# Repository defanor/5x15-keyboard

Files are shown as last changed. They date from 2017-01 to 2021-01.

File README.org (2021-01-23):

* A 5x15 keyboard
This is a keyboard project. That's also my first hardware project, so
in case if somebody would want to reuse it, be careful. Though I've
built it and it works.

The keyboard has 5 rows and 15 columns (well, depends on how one
counts, but approximately that much), and intended to be handy for
emacs: has plenty of accessible modifier keys, and never requires to
get too far from the home row.

More information, photos, and the build process description can be
found in the "[[https://defanor.uberspace.net/notes/building-a-keyboard.xhtml][building a keyboard]]" note.

** Dependencies and software
The switches are borrowed from [[https://www.ergodox.io/][ergodox]] (and altered a bit), and the
[[https://github.com/LuisDiazUgena/Teensy-3.1][LuisDiazUgena/Teensy-3.1]] library for kicad is used. KiCad and LibreCAD
were used, by the way.

For the firmware, I've used PaulStoffregen/{[[https://github.com/PaulStoffregen/cores][cores]],
[[https://github.com/PaulStoffregen/teensy_loader_cli][teensy_loader_cli]]}. Changes introduced to ~teensy3/Makefile~:

#+BEGIN_EXAMPLE
 # configurable options
-OPTIONS = -DF_CPU=48000000 -DUSB_SERIAL -DLAYOUT_US_ENGLISH -DUSING_MAKEFILE
+OPTIONS = -DF_CPU=48000000 -DUSB_KEYBOARDONLY -DLAYOUT_US_ENGLISH -DUSING_MAKEFILE
#+END_EXAMPLE

Then it can be built with ~NO_ARDUINO=1 make~.

** License
Hopefully without violating licenses of the reused bits, this project
is GPL-licensed.

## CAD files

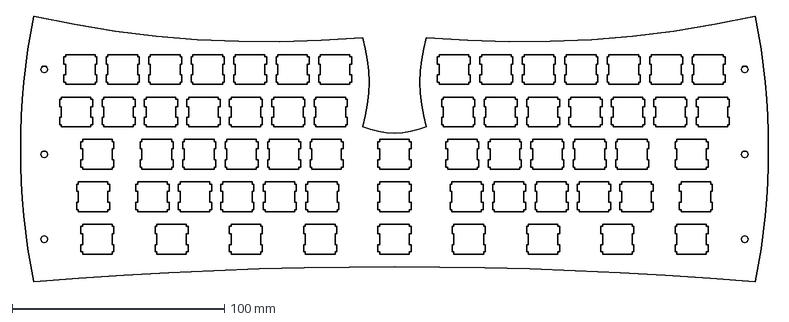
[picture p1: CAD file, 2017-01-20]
dxf/metal-plate-curved-out.dxf
356.5 x 125.0 mm

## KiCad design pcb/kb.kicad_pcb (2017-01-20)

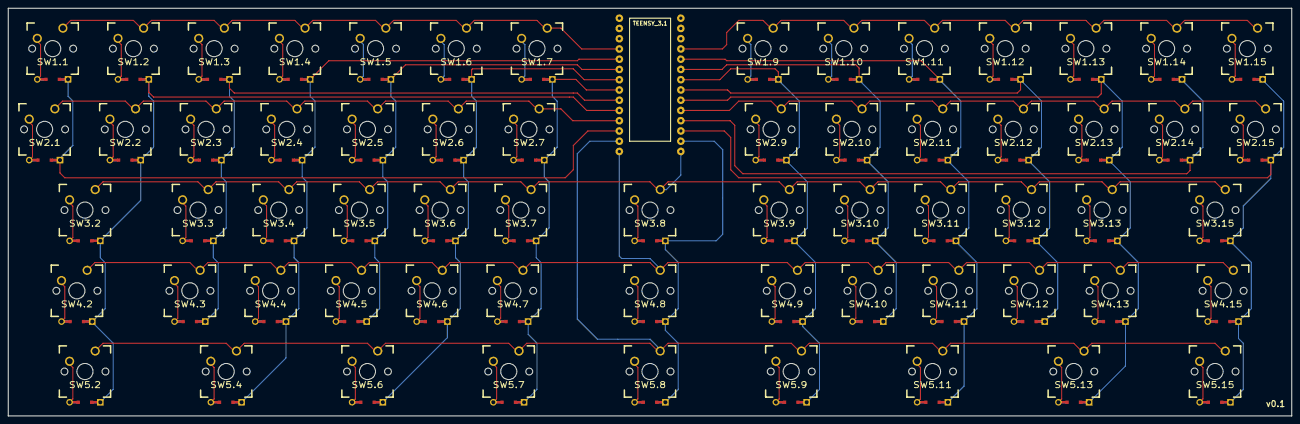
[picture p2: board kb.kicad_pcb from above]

Board: 2 copper layers, 318.0 x 101.0 mm, 64 parts (0 on the bottom side), 85 nets.

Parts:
SW1.1, SW1.2, SW1.3, SW1.4, SW1.5, SW1.6, SW1.7, SW1.9, SW1.10, SW1.11, SW1.12, SW1.13, SW1.14, SW1.15, SW2.1, SW2.2, SW2.3, SW2.4, SW2.5, SW2.6, SW2.7, SW2.9, SW2.10, SW2.11, SW2.12, SW2.13, SW2.14, SW2.15, SW3.3, SW3.4, SW3.5, SW3.6, SW3.7, SW3.9, SW3.10, SW3.11, SW3.12, SW3.13, SW4.3, SW4.4, SW4.5, SW4.6, SW4.7, SW4.9, SW4.10, SW4.11, SW4.12, SW4.13: SWITCH_DIODE; MX_FLIP_DIODE
SW3.2, SW3.8, SW3.15, SW4.2, SW4.8, SW4.15, SW5.2, SW5.4, SW5.6, SW5.7, SW5.8, SW5.9, SW5.11, SW5.13, SW5.15: SWITCH_DIODE; MX_FLIP_DIODE_1_75
U1: TEENSY_3.1

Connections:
/col-1: SW1.1.4, SW2.1.4, U1.10
/col-2: SW1.2.4, SW2.2.4, SW3.2.4, SW4.2.4, SW5.2.4, U1.8
/col-3: SW1.3.4, SW2.3.4, SW3.3.4, SW4.3.4, U1.7
/col-4: SW1.4.4, SW2.4.4, SW3.4.4, SW4.4.4, SW5.4.4, U1.3
/col-5: SW1.5.4, SW2.5.4, SW3.5.4, SW4.5.4, U1.4
/col-6: SW1.6.4, SW2.6.4, SW3.6.4, SW4.6.4, SW5.6.4, U1.5
/col-7: SW1.7.4, SW2.7.4, SW3.7.4, SW4.7.4, SW5.7.4, U1.6
/col-8: SW3.8.4, SW4.8.4, SW5.8.4, U1.14
/col-9: SW1.9.4, SW2.9.4, SW3.9.4, SW4.9.4, SW5.9.4, U1.20
/col-10: SW1.10.4, SW2.10.4, SW3.10.4, SW4.10.4, U1.21
/col-11: SW1.11.4, SW2.11.4, SW3.11.4, SW4.11.4, SW5.11.4, U1.22
/col-12: SW1.12.4, SW2.12.4, SW3.12.4, SW4.12.4, U1.19
/col-13: SW1.13.4, SW2.13.4, SW3.13.4, SW4.13.4, SW5.13.4, U1.18
/col-14: SW1.14.4, SW2.14.4, U1.16
/col-15: SW1.15.4, SW2.15.4, SW3.15.4, SW4.15.4, SW5.15.4, U1.15
/row-1-left: SW1.1.1, SW1.2.1, SW1.3.1, SW1.4.1, SW1.5.1, SW1.6.1, SW1.7.1, U1.2
/row-1-right: SW1.9.1, SW1.10.1, SW1.11.1, SW1.12.1, SW1.13.1, SW1.14.1, SW1.15.1, U1.23
/row-2-left: SW2.1.1, SW2.2.1, SW2.3.1, SW2.4.1, SW2.5.1, SW2.6.1, SW2.7.1, U1.9
/row-2-right: SW2.9.1, SW2.10.1, SW2.11.1, SW2.12.1, SW2.13.1, SW2.14.1, SW2.15.1, U1.17
/row-3: SW3.2.1, SW3.3.1, SW3.4.1, SW3.5.1, SW3.6.1, SW3.7.1, SW3.8.1, SW3.9.1, SW3.10.1, SW3.11.1, SW3.12.1, SW3.13.1, SW3.15.1, U1.13
/row-4: SW4.2.1, SW4.3.1, SW4.4.1, SW4.5.1, SW4.6.1, SW4.7.1, SW4.8.1, SW4.9.1, SW4.10.1, SW4.11.1, SW4.12.1, SW4.13.1, SW4.15.1, U1.12
/row-5: SW5.2.1, SW5.4.1, SW5.6.1, SW5.7.1, SW5.8.1, SW5.9.1, SW5.11.1, SW5.13.1, SW5.15.1, U1.11
unnamed: SW1.9.2, SW1.9.3
unnamed: SW2.9.2, SW2.9.3
unnamed: SW3.9.2, SW3.9.3
unnamed: SW4.9.2, SW4.9.3
unnamed: SW5.9.2, SW5.9.3
unnamed: SW3.8.2, SW3.8.3
unnamed: SW4.8.2, SW4.8.3
unnamed: SW5.8.2, SW5.8.3
unnamed: SW4.11.2, SW4.11.3
unnamed: SW3.10.2, SW3.10.3
unnamed: SW2.10.2, SW2.10.3
unnamed: SW1.10.2, SW1.10.3
unnamed: SW1.11.2, SW1.11.3
unnamed: SW2.11.2, SW2.11.3
unnamed: SW3.11.2, SW3.11.3
unnamed: SW4.10.2, SW4.10.3
unnamed: SW5.11.2, SW5.11.3
unnamed: SW1.5.2, SW1.5.3
unnamed: SW2.5.2, SW2.5.3
unnamed: SW3.5.2, SW3.5.3
unnamed: SW4.5.2, SW4.5.3
unnamed: SW1.6.2, SW1.6.3
unnamed: SW2.6.2, SW2.6.3
unnamed: SW3.6.2, SW3.6.3
unnamed: SW3.4.2, SW3.4.3
unnamed: SW1.4.2, SW1.4.3
unnamed: SW2.4.2, SW2.4.3
unnamed: SW4.4.2, SW4.4.3
unnamed: SW5.4.2, SW5.4.3
unnamed: SW1.7.2, SW1.7.3
unnamed: SW2.7.2, SW2.7.3
unnamed: SW3.7.2, SW3.7.3
unnamed: SW4.7.2, SW4.7.3
unnamed: SW5.7.2, SW5.7.3
unnamed: SW4.6.2, SW4.6.3
unnamed: SW5.6.2, SW5.6.3
unnamed: SW4.15.2, SW4.15.3
unnamed: SW5.15.2, SW5.15.3
unnamed: SW5.13.2, SW5.13.3
unnamed: SW5.2.2, SW5.2.3
unnamed: SW3.12.2, SW3.12.3
unnamed: SW4.12.2, SW4.12.3
unnamed: SW2.12.2, SW2.12.3
unnamed: SW1.12.2, SW1.12.3
unnamed: SW1.14.2, SW1.14.3
unnamed: SW1.15.2, SW1.15.3
unnamed: SW2.15.2, SW2.15.3
unnamed: SW1.13.2, SW1.13.3
unnamed: SW2.13.2, SW2.13.3
unnamed: SW3.13.2, SW3.13.3
unnamed: SW4.13.2, SW4.13.3
unnamed: SW3.15.2, SW3.15.3
unnamed: SW2.14.2, SW2.14.3
unnamed: SW4.2.2, SW4.2.3
unnamed: SW2.2.2, SW2.2.3
unnamed: SW3.3.2, SW3.3.3
unnamed: SW4.3.2, SW4.3.3
unnamed: SW1.1.2, SW1.1.3
unnamed: SW1.2.2, SW1.2.3
unnamed: SW1.3.2, SW1.3.3
unnamed: SW2.1.2, SW2.1.3
unnamed: SW3.2.2, SW3.2.3
unnamed: SW2.3.2, SW2.3.3

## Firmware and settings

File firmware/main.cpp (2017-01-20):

#include "WProgram.h"
#include "keys.h"

// [esc] [ ~ ] [ 1 ] [ 2 ] [ 3 ] [ 4 ] [ 5 ]             [ 6 ] [ 7 ] [ 8 ] [ 9 ] [ 0 ] [ - ] [ + ]
// [ \ ] [ / ] [ q ] [ w ] [ f ] [ p ] [ g ]             [ j ] [ l ] [ u ] [ y ] [ ; ] [ [ ] [ ] ]
//   [ shift ] [ a ] [ r ] [ s ] [ t ] [ d ]  [  tab  ]  [ h ] [ n ] [ e ] [ i ] [ o ] [ shift ]
//   [control] [ z ] [ x ] [ c ] [ v ] [ b ]  [ bkspc ]  [ k ] [ m ] [ , ] [ . ] [ ' ] [control]
//   [ meta  ] [       ] [ layout] [  alt  ]  [  ret  ]  [ space ] [layout ] [ altgr ] [ meta  ]

uint8_t keymap[3][7][15] = {
  { // qwerty
    {K_ESC,    K_TILDE, K_1, K_2, K_3, K_4, K_5, 0,      0,     0,   0,       0,     0,       0,        0},
    {0,        0,       0,   0,   0,   0,   0,   0,      K_6,   K_7, K_8,     K_9,   K_0,     K_MINUS,  K_EQUAL},
    {K_BSLASH, K_SLASH, K_Q, K_W, K_E, K_R, K_T, 0,      0,     0,   0,       0,     0,       0,        0},
    {0,        0,       0,   0,   0,   0,   0,   0,      K_Y,   K_U, K_I,     K_O,   K_P,     K_LBRACE, K_RBRACE},
    {0,        0,       K_A, K_S, K_D, K_F, K_G, K_TAB,  K_H,   K_J, K_K,     K_L,   K_SCOL,  0,        0},
    {0,        0,       K_Z, K_X, K_C, K_V, K_B, K_BSPC, K_N,   K_M, K_COMMA, K_DOT, K_QUOTE, 0,        0},
    {0,        0,       0,   0,   0,   0,   0,   K_RET,  K_SPC, 0,   0,       0,     0,       0,        0}
  },
  { // mostly functional keys
    // ESC, DEL, and F*
    {K_ESC, K_DEL, K_F1,    K_F2,   K_F3,   K_F4,   K_F5,  0,     0,     0,       0,    0,       0,       0,     0},
    {0,     0,     0,       0,      0,      0,      0,     0,     K_F6,  K_F7,    K_F8, K_F9,    K_F10,   K_F11, K_F12},
    // nothing for now
    {0,     0,     0,       0,      0,      0,      0,     0,     0,      0,      0,    0,       0,       0,     0},
    {0,     0,     0,       0,      0,      0,      0,     0,     0,      0,      0,    0,       0,       0,     0},
    // hjkl-style navigation keys
    {0,     0,     0,       K_HOME, K_PGUP, K_PGDN, K_END, K_TAB, K_LEFT, K_DOWN, K_UP, K_RIGHT, 0,       0,     0},
    // nothing for now
    {0,     0,     0,       0,      0,      0,      0,     K_BSPC,0,      0,      0,    0,       0,       0,     0},
    {0,     0,     0,       0,      0,      0,      0,     K_RET, K_SPC,  0,      0,    0,       0,       0,     0}
  },
  { // colemak
    {K_ESC,    K_TILDE, K_1, K_2, K_3, K_4, K_5, 0,      0,     0,   0,       0,     0,       0,        0},
    {0,        0,       0,   0,   0,   0,   0,   0,      K_6,   K_7, K_8,     K_9,   K_0,     K_MINUS,  K_EQUAL},
    {K_BSLASH, K_SLASH, K_Q, K_W, K_F, K_P, K_G, 0,      0,     0,   0,       0,     0,       0,        0},
    {0,        0,       0,   0,   0,   0,   0,   0,      K_J,   K_L, K_U,     K_Y,   K_SCOL,  K_LBRACE, K_RBRACE},
    {0,        0,       K_A, K_R, K_S, K_T, K_D, K_TAB,  K_H,   K_N, K_E,     K_I,   K_O,     0,        0},
    {0,        0,       K_Z, K_X, K_C, K_V, K_B, K_BSPC, K_K,   K_M, K_COMMA, K_DOT, K_QUOTE, 0,        0},
    {0,        0,       0,   0,   0,   0,   0,   K_RET,  K_SPC, 0,   0,       0,     0,       0,        0}
  }
};

uint8_t p[7][15]; // pressed keys
uint8_t prev_keys[6] = {0,0,0,0,0,0}, prev_modifiers = 0;
uint8_t layout = 0;
uint8_t layout_state = 0;

int type () {
  uint8_t i, j, ret = 0, k = 0, send = 0, cur_layout = layout;

  // Set modifiers
  keyboard_modifier_keys =
    p[5][1]           // left ctrl
    | (p[4][1] << 1)  // left shift
    | (p[6][6] << 2)  // left alt
    | (p[6][1] << 3)  // left "gui"
    | (p[5][14] << 4) // right ctrl
    | (p[4][14] << 5) // right shift
    | (p[6][12] << 6) // right alt
    | (p[6][14] << 7) // right "gui"
    ;

  // Handle layout keys
  if (p[6][5] && p[6][10]) {
    if (layout_state == 0) {
      // Cycle through layouts. Perhaps should track the order in
      // which Fn keys are pressed, to determine the direction.
      layout = (layout + 1) % 3;
      cur_layout = layout;
      layout_state = 1;
    }
  } else if (p[6][5] || p[6][10]) {
    // Set the functional layout temporary
    cur_layout = 1;
  } else {
    layout_state = 0;
  }

  // Fill keyboard_keys
  for (i = 0; i < 7; i++){
    for (j = 0; j < 15; j++){
      if (p[i][j] && k < 6) {
        if (keymap[layout][i][j]) {
          keyboard_keys[k] = keymap[cur_layout][i][j];
          k++;
        }
      }
    }
  }
  while (k < 6) {
    keyboard_keys[k] = 0;
    k++;
  }

  // Compare it to the previously sent keys, send if they differ
  for (k = 0; k < 6; k++)
    if (prev_keys[k] != keyboard_keys[k])
      send = 1;
  if (prev_modifiers != keyboard_modifier_keys)
    send = 1;

  if (send)
    ret = usb_keyboard_send();

  prev_modifiers = keyboard_modifier_keys;
  for (k = 0; k < 6; k++)
    prev_keys[k] = keyboard_keys[k];

  return ret;
}


extern "C" int main(void) {
  uint8_t i = 0, j = 0, s = 0;
  uint8_t row_pins[7] = {2, 23, 9, 17, 13, 12, 11};
  uint8_t col_pins[15] = {10, 8, 7, 3, 4, 5, 6, 14, 20, 21, 22, 19, 18, 16, 15};

  for (i=0; i < 7; i ++) {
    pinMode(row_pins[i], OUTPUT);
    digitalWriteFast(row_pins[i], LOW);
  }
  for (i=0; i < 15; i ++) {
    pinMode(col_pins[i], INPUT_PULLDOWN);
  }

  while (1) {
    for (i = 0; i < 7; i++) {
      digitalWriteFast(row_pins[i], HIGH);
      for (j = ((i == 1 || i == 3) ? 8 : 0);
           j < ((i == 0 || i == 2) ? 7 : 15);
           j++)
        {
          s = digitalReadFast(col_pins[j]);
          p[i][j] = s;
        }
      digitalWriteFast(row_pins[i], LOW);
    }
    type();
    delay(5);
  }
}
